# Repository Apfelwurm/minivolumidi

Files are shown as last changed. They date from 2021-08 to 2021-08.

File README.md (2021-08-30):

# minivolumidi Project

minivolumidi is a simple midi controller via wifi and [rtpMIDI](https://www.tobias-erichsen.de/software/rtpmidi.html) / apple network MIDI, based on a [Wemos D1 mini (ESP8266)](https://www.wemos.cc/en/latest/d1/d1_mini.html) and a KY-40 rotary encoder that is intended to act as a volume controller. By default a short button press sets the CC value to the configured ``MIN_POS`` and a long button press sets it back to the value before the short button press.

This project is based on the following sources:
* https://github.com/lathoub/Arduino-AppleMIDI-Library/tree/master/examples
* https://github.com/LennartHennigs/ESPRotary/tree/master/examples
* https://github.com/FortySevenEffects/arduino_midi_library/tree/master/examples
* https://www.thingiverse.com/thing:2814909
* https://www.thingiverse.com/thing:3646462

Thanks to all the nice people making qick projects like this possible by their contributions to the open source world! 

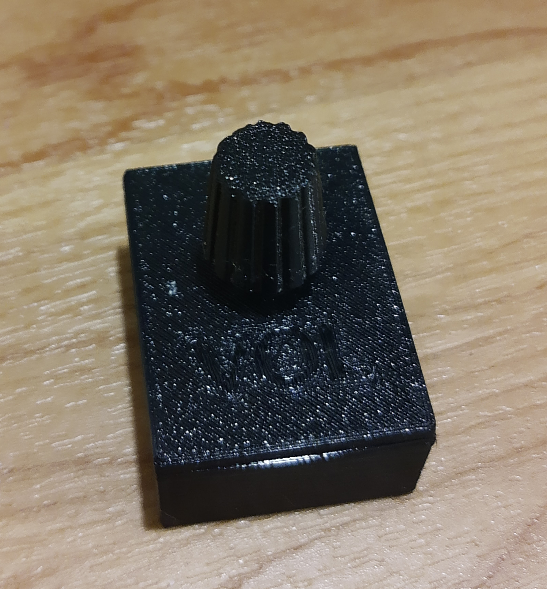
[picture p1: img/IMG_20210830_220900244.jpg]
minivolumidi

(more pictures in the ``img`` folder)

## prerequirements for building the hardware

* [Wemos D1 mini (ESP8266)](https://www.wemos.cc/en/latest/d1/d1_mini.html)
* a micro usb cable
* a KY-40 rotary encoder
* some wires
* soldering iron
* a 3d printer (if you want to print the case for it)
* hot glue gun
## prerequirements for building the software

* install [Platformio Core](https://docs.platformio.org/en/latest/core/installation.html) or [Platformio IDE](https://docs.platformio.org/en/latest/integration/ide/vscode.html#ide-vscode) (which installes Pio core automatically)
* clone this repository
```
git clone https://github.com/Apfelwurm/minivolumidi.git
```
## build (Visual Studio Code)

* open the cloned repo in VSCode

```
code minivolumidi
```

* open the ``src/main.cpp`` file and adapt the values in the configure section according to your requirements. 
* open the ``platformio.ini`` file and change the ``upload_port`` to your needs (most likely ``/dev/ttyUSB0`` on linux and ``COM3`` on windows)
* Press f5 to build it.
* Press the ``PlatformIO:Upload`` button at the bottom navigation of vscode to flash your wemos d1.

## build (CLI)

You can instead go to the repo folder with your terminal and run

```
pio run
```

respectively

```
pio run -t upload
```

depending if you want to just build or directly upload it to your wemos d1.

## enclosure

You can find a 3d printable enclosure and the rotary encoder knob files in the ``case`` subdirectory.
To print everything you can just use the ``case/wemos_stack_with_rotary_knob.stl`` in your favorite slicer.
For customizing of the case or if you dont want to print the knob, look into the ``case/wemos_stack.scad`` and adjust it to your needs.

## building the hardware

* print your case
* flash your Wemos d1
* bend the pins on your KY-40 rotary encoder so they face in the opposite direction as the rotary encoder or desolder them
* solder the KY-40s + pin to 3.3v of the Wemos
* solder the KY-40s GND pin to GND of the Wemos
* solder the KY-40s SW pin to configured ``BUTTON_PIN`` of the Wemos (dont use D8!) (default D5)
* solder the KY-40s CLK pin to configured ``ROTARY_PIN2`` of the Wemos (default D7)
* solder the KY-40s DT pin to configured ``ROTARY_PIN1`` of the Wemos (default D6)
* insert the KY-40 into the lid of the case (maybe you have to widen the hole a little bit for that)
* try to shorten the outstanding KY-40s pins on the bottom (be careful that you dont break something)
* fill the gapps between the KY40 and the lid with hotglue as good as possible and cover the whole back of the KY-40 with a 3-4mm thick layer of it. Be careful to clean all hot glue that will block the lids closing mechanism
* put the wemos in the case and close the lid with the KY-40 by pressing it together with the case
* put some hotglue into the rotary knob and press it on the rotary encoder
## using the hardware on windows

* install [rtpMIDI](https://www.tobias-erichsen.de/software/rtpmidi.html) on your target machine
* initially connect your minivolumidi via usb to your pc, open a serial terminal and press the small reset button on the left side with a needle. You should now get a serial print out of the IP address, the name and the port of your minivolumidi. 
* open rtpMIDI, add a session on the left side and enable it on the right side.
* add the minivolumidi in the ``Directory`` section with the data you gathered from the serial terminal
* press connect and test if it shows the connected client with a latency on the right side
* if everything works, you can now power the wemos everywhere in the wifi range of the configured network, without the usb connection and connect it via rtpMIDI
* open your DAW of choise and enable the rtpMIDI input and output channels
* map the midi parameter to whatever you want to control with it. Because of the wifi latency its not really useful for instant controls, but its perfect as a simple volume controller.

## contributions

if you want to contribute to the project or if you have problems, dont hesitate to open issues or submit pull requests.

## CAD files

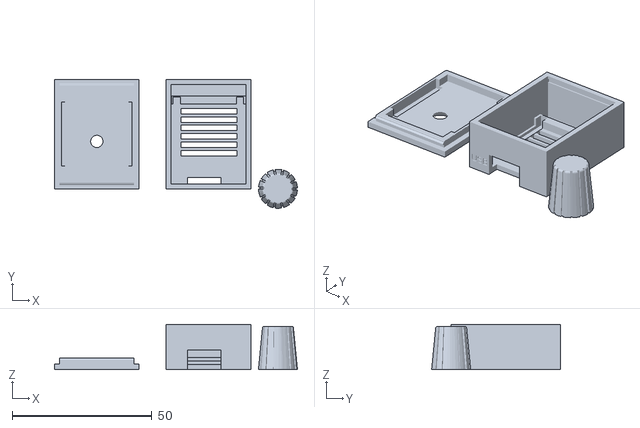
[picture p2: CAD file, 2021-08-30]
case/wemos_stack_with_rotary_knob.stl
87.0 x 46.1 x 16.2

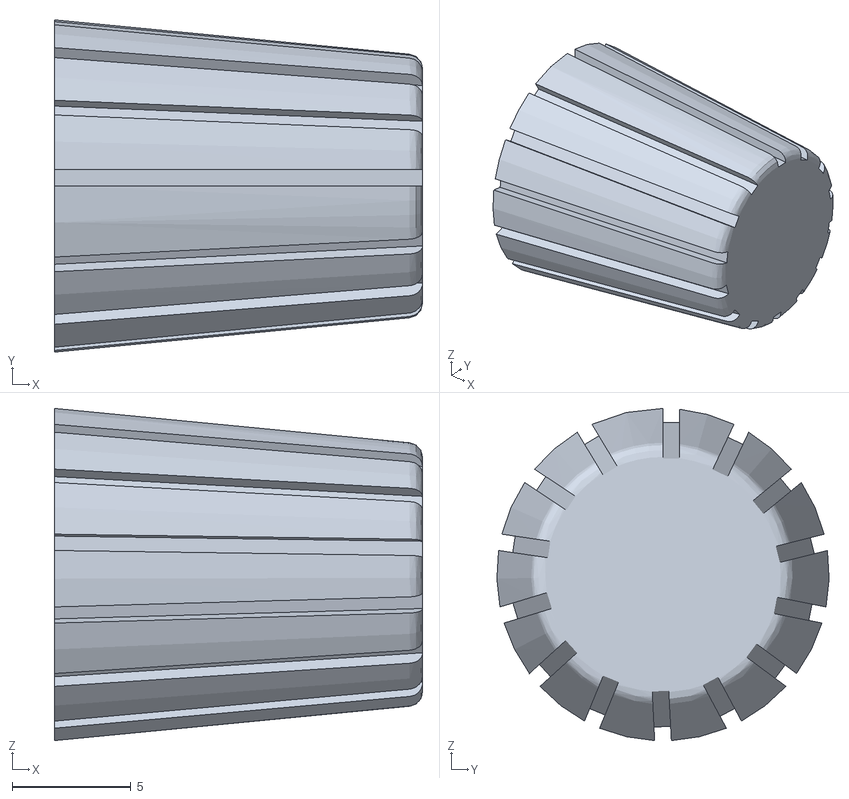
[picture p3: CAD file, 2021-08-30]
case/Drehregler7.stl
15.5 x 14.0 x 14.0

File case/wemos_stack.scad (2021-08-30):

// This Version is based on https://www.thingiverse.com/thing:2814909 and the Rotary Encoder Cap is used from https://www.thingiverse.com/thing:3646462
//
// WeMOS D1 Mini Stack Enclosure Script
// This Version is inspired from https://www.thingiverse.com/thing:1776349/#files
//
// This script was written to generate a suitable 3D printed enclosure for a WeMOS "stack" of shields.
// Since there are a variety of connectors, sizes and arrangements, the decission was to let the customizer
// allow for various positionings of each shields port.
//
// To use, you will need to assemble your device put it on a flat surface (e.g. table) and measureeach layer. 
// For measuring you need the distance from your flat surface to the lower end of the opening in the case.
//  - the total innerSizeZ (height) of the stack
//  - the inner offsets for any shields that require an opening in the case.
//
// For instance, We have the following Stack:
//
// +----------------+
// | SD Card Shield |
// +----------------+
// | Battery Shield |
// +----------------+
// | WeMOS D1 Mini  |
// +----------------+ 2 mm
//
// All have stackable headers, that have had their pins trimmed to make the stack as short
// as possible.  The resulting measurements of the stack yield the default values of this script.
//

/* [inner Height Z] */
// Final height of the stack measured when placing the sole stack on a flat surface.
//innerHeightZ = 58.7;
innerHeightZ = 14.4;


/* [Shield Ports] */

// Distance from the bottom of PCB Board to the bottom of the usb connector opening (-99 to omit)
usbHeight = -1.0;

// Distance from the bottom of PCB Board to the bottom of the microsd shield opening (-99 to omit)
//microsdHeight = 30;
// microsdHeight = 8;
 microsdHeight = -99;

// Distance from the bottom of PCB Board to the bottom of the battery shield connector opening (-99 to omit)
//batteryHeight = 18.0;
//batteryHeight = 15;
batteryHeight = -99;

// Distance from the bottom of PCB Board to the bottom of the DC Power shield connector terminal opening (-99 to omit)
//dcPowerHeight=25;
dcPowerHeight=-99;

// Distance from the bottom of PCB Board to the bottom of the relay shield connector terminal opening (-99 to omit)
relayHeight = 38.0;

// Show Base housing
showBase=true;

/* [LID] */

// There are visible cutouts in the lid for 
lidHasVisiblePinoutSlits=false;

// The lid should contain a cutout connecting the PINs
lidCutOutType="LED"; // [ LCD:LCD Shield , DHT:Dht Shield,DHThorizontal:Dht Shield, BUTTON:Button Shield , NONE:No cutout]

// Do you want the Lid to show up
showLid=true;

//Side and Front slits for letting warm air out
airSlits=false;

/* [Others] */
wallThickness = 1.8;

// cut through at Bottom for Pins
bottomHasPinoutSlits=true;

// Add mounting clips with screw holes a bottom
numberOfBaseMountingClips=0;

// show some Examples
showExamples=false;

// show each Tape once
showAllOnce=false;

// ---------------------------------------------------------------------------------------------------------
// do not need to modify anything below here
// ---------------------------------------------------------------------------------------------------------
/* [Hidden] */

extraGap=0.2;
printerWobble=0.01;
printerWobbleXYZ=printerWobble*[1,1,1];
printerWobbleXYZ2=printerWobbleXYZ*2;

$fn=20;

// Final outerSizeZ of the stack walls.
// outerSizeZ = 36.0;

innerSizeX = 26.70;
innerSizeY = 35.5;
//innerSizeZ = innerHeightZ;


holeDiameter = 20.0;

// Offset of all stacked Boards because of the WIFI Antenna
antennaOffsetY=6.2;
lcdDimensions=[18.5,18.1,4.5]
              +2*printerWobble*[1,1,0];

// Size of the slits for pins of PCB board
slitDimension=[2.6,23.0,10.0];


/* calculated */
extraGap2=2*extraGap;


// ===================================================
// Rotary knob - https://www.thingiverse.com/thing:3646462
// ===================================================

translate([40,0,0])rotate([0,270,0])
import("Drehregler7.stl");

// ===================================================
// Main
// ===================================================

if (showAllOnce){
    translate([0,-50,0])  
        LidExamples();
    
    BaseExamples();

} else {

    // base
    if (showBase)
        base(innerSizeZ=innerHeightZ-wallThickness,numberOfBaseMountingClips=numberOfBaseMountingClips);

    // lid
    if (showLid)
        translate([-40,0,0])   
            lid(lidCutOutType=lidCutOutType);


    // All kind of examples
    if ( showExamples)
        translate([0,200,0])  
            examples();

}

// ===================================================
// Modules
// ===================================================

module examples(){
    translate([0,-50,0])  {
        LidExamples();
    translate([0,-45,40])  
        rotate([270,0,0]) 
            LidExamples();
    }
    
    BaseExamples();

}


module BaseExamples(){
        translate([0,0,0])   {
            translate([000,0,0])     base(innerSizeZ=17,        numberOfBaseMountingClips=0);
            translate([050,0,0])     base(innerSizeZ=17,        numberOfBaseMountingClips=2);
            translate([100,0,0])     base(innerSizeZ=17,        numberOfBaseMountingClips=4);
        }
        
        translate([0,60,0])  {
            translate([000,0,0])     base(innerSizeZ=12.5, numberOfBaseMountingClips=0);
            translate([040,0,0])     base(innerSizeZ=22.5, numberOfBaseMountingClips=0);
            translate([080,0,0])     base(innerSizeZ=36,   numberOfBaseMountingClips=0);
            translate([120,0,0])     base(innerSizeZ=47,   numberOfBaseMountingClips=0);
        }
        
        translate([0,120,0])   {
            translate([000,0,0])     base(innerSizeZ=27);
            translate([040,0,0])     base(innerSizeZ=27, dcPowerHeight=12,  microsdHeight=0, batteryHeight=0, relayHeight=0 , numberOfBaseMountingClips=0);
            translate([080,0,0])     base(innerSizeZ=27, dcPowerHeight=0,  microsdHeight=12, batteryHeight=0, relayHeight=0 , numberOfBaseMountingClips=0);
            translate([120,0,0])     base(innerSizeZ=27, dcPowerHeight=0,  microsdHeight=0, batteryHeight=12, relayHeight=0 , numberOfBaseMountingClips=0);
            translate([160,0,0])     base(innerSizeZ=27, dcPowerHeight=0,  microsdHeight=0, batteryHeight=0, relayHeight=12 , numberOfBaseMountingClips=0);
        }

}

module LidExamples(){
        translate([000,0,0])   lid(lidCutOutType="BUTTON");
        translate([040,0,0])   lid(lidCutOutType="LCD");
        translate([080,0,0])   lid(lidCutOutType="DHT");
        translate([120,0,0])   lid(lidCutOutType="HOLE");
        translate([160,0,0])   lid(lidCutOutType="NONE");

}


module lcdCutOut(){
   cube(lcdDimensions+extraGap*[1,1,0]);

    // Flat cable for connection
    cableX=14;
    cableY=6;
    cableZ=4;
    translate([lcdDimensions[0]/2-cableX/2,-cableY+.001,.5])
        cube([cableX,cableY,cableZ]);
}


module pinHoleSlits(visibleFromOutside=1){
    
    slitOffsetY=wallThickness
                +innerSizeY
                -slitDimension[1]
                -antennaOffsetY;
    
    translate([0,0,visibleFromOutside==1?-.01:+.8])
        translate([.7,slitOffsetY,0])
            for ( x=[0,22.6]){
                translate([x,0,0])
                    cube(slitDimension);
            }
}


// ========================================
// Lid
// ========================================

module lid(lidCutOutType="BUTTON"){
    outerSizeX = innerSizeX + (2 * wallThickness);
    outerSizeY = innerSizeY + (2 * wallThickness);
//    outerSizeZ = innerSizeZ + (2 * wallThickness);
    diameterButton=8;
    
    difference() {
        union () {
            // Lid Base Plate
            translate([0, 0, 0.0]) cube([outerSizeX, outerSizeY, 2.0]);

            // Lid inner part
            translate([ wallThickness+printerWobble, wallThickness+printerWobble,wallThickness]) {
                color("green")
                    cube([innerSizeX-2*printerWobble, innerSizeY-2*printerWobble, 2.3]);
                LidNotch(wobble=-1);
             }
        }
        
        // Space for PCB Board
        innerFrameOffset=2;
        translate([ wallThickness+innerFrameOffset, wallThickness+innerFrameOffset,wallThickness]) 
                cube([innerSizeX-innerFrameOffset*2, innerSizeY-innerFrameOffset*2, 4]);
        
        translate([wallThickness,0,0])
            pinHoleSlits(visibleFromOutside=lidHasVisiblePinoutSlits);
        
        // Lid Cutout
        if(lidCutOutType=="LCD"){
                translate(wallThickness*[1,1,-0.001]
                        +[innerSizeX/2,innerSizeY,0])
                        translate([-lcdDimensions[0]/2,-lcdDimensions[1],0]
                                  +[0,-antennaOffsetY,0]
                                ) 
                            lcdCutOut();
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

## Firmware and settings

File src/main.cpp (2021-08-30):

// minivolumidi main script
// packed together by Apfelwurm <Alexander@volzit.de>
// based on the following sources:
// https://github.com/lathoub/Arduino-AppleMIDI-Library/tree/master/examples
// https://github.com/LennartHennigs/ESPRotary/tree/master/examples
// https://github.com/FortySevenEffects/arduino_midi_library/tree/master/examples

#include <ESP8266WiFi.h>
#include <WiFiClient.h>
#include <WiFiUdp.h>
#include <AppleMIDI.h>
#include <Arduino.h>
#include "Button2.h" 
#include "ESPRotary.h"

/////////////////////////////////////////////////////////////////
// Configure your needs here
/////////////////////////////////////////////////////////////////
char ssid[] = "SSID"; //  your network SSID (name)
char pass[] = "PASSWORD";    // your network password (use for WPA, or use as key for WEP)


#define ROTARY_PIN1 D6 // DT pin of ky-040
#define ROTARY_PIN2 D7 // CLK pin of ky-040
#define BUTTON_PIN  D5 // SW pin of ky-040

#define CLICKS_PER_STEP 2   // this number depends on your rotary encoder
#define MIN_POS         0   // minimum value for the knob
#define MAX_POS         127 // maximum value for the knob
#define START_POS       20  // starting position for the knob
#define INCREMENT       1   // this number is the counter increment on each step

#define MIDI_CC         91  //CC Number that should be used
#define MIDI_CHANNEL    1   // Midi Channel that should be used
/////////////////////////////////////////////////////////////////

/////////////////////////////////////////////////////////////////
// varible initialisation
/////////////////////////////////////////////////////////////////
bool newpos = false;
bool mute = false;
bool unmute = true;
unsigned long t0 = millis();
int8_t isConnected = 0;
/////////////////////////////////////////////////////////////////

/////////////////////////////////////////////////////////////////
// object initialisation
/////////////////////////////////////////////////////////////////
APPLEMIDI_CREATE_DEFAULTSESSION_INSTANCE();
ESPRotary r;
Button2 b;    // https://github.com/LennartHennigs/Button2
/////////////////////////////////////////////////////////////////



/////////////////////////////////////////////////////////////////
// Rotary encoder functions
/////////////////////////////////////////////////////////////////

// on change
void rotate(ESPRotary& r) {
   Serial.println(r.getPosition());
   newpos = true;
}

// on left or right rotation
void showDirection(ESPRotary& r) {
  Serial.println(r.directionToString(r.getDirection()));
}

// single click
void click(Button2& btn) {
  mute=true;
  Serial.println("Click!");
}

// long click
void resetPosition(Button2& btn) {
  unmute = true;
  Serial.println("Reset!");
}

/////////////////////////////////////////////////////////////////


/////////////////////////////////////////////////////////////////
// setup
/////////////////////////////////////////////////////////////////
void setup() {

  //serial setup
  Serial.begin(115200);

  delay(50);

  //wifi setup
  WiFi.begin(ssid, pass);

  while (WiFi.status() != WL_CONNECTED) {
    delay(500);
    Serial.println("Establishing connection to WiFi..");
  }
  Serial.println("Connected to network");

  //RTP Midi setup
  Serial.println(F("OK, now make sure you an rtpMIDI session that is Enabled"));
  Serial.println(WiFi.localIP().toString()); 
  Serial.println(AppleMIDI.getPort()); 
  Serial.println(AppleMIDI.getName()); 
  Serial.println(F("Select and then press the Connect button"));
  Serial.println(F("Then open a MIDI listener and monitor incoming notes"));
  Serial.println(F("Listen to incoming MIDI commands"));
 
  MIDI.begin();
  
 AppleMIDI.setHandleConnected([](const APPLEMIDI_NAMESPACE::ssrc_t & ssrc, const char* name) {
    isConnected++;
    Serial.println(F("Connected to session"));
    Serial.println(ssrc); 
    Serial.println(name); 

  });
  AppleMIDI.setHandleDisconnected([](const APPLEMIDI_NAMESPACE::ssrc_t & ssrc) {
    isConnected--;
    Serial.println(F("Disconnected"));
    Serial.println(ssrc); 
  });
  
 
  //button setup
  b.begin(BUTTON_PIN);
  b.setTapHandler(click);
  b.setLongClickHandler(resetPosition);

  //rotary setup
  r.begin(ROTARY_PIN1, ROTARY_PIN2, CLICKS_PER_STEP, MIN_POS, MAX_POS, START_POS, INCREMENT);
  r.setChangedHandler(rotate);
  r.setLeftRotationHandler(showDirection);
  r.setRightRotationHandler(showDirection);

  //init output
  Serial.println("\n\nminivolumidi");
  Serial.println("Is configured for values between " + String(MIN_POS) + " and " + String(MAX_POS) +".");
  Serial.print("Increment: ");
  Serial.println(r.getIncrement());
  Serial.print("Current position: ");
  Serial.println(r.getPosition());
  Serial.println();
}
/////////////////////////////////////////////////////////////////


/////////////////////////////////////////////////////////////////
// loop
/////////////////////////////////////////////////////////////////
void loop() {
  
  //RTPMIDI processing
  MIDI.read();

  //rotary processing
  r.loop();

  //button processing
  b.loop();

  if ((isConnected > 0) && (millis() - t0) > 1000)
  {
    t0 = millis();

    // mute and unmute
    if (mute){
      MIDI.sendControlChange((byte)MIDI_CC,(byte)MIN_POS,MIDI_CHANNEL);
      mute=false;
    }
    if (unmute)
    {     
      MIDI.sendControlChange((byte)MIDI_CC,(byte)r.getPosition(),MIDI_CHANNEL);
      unmute=false;
    }

    // value update
    if (newpos)
    {
      MIDI.sendControlChange((byte)MIDI_CC,(byte)r.getPosition(),MIDI_CHANNEL);
      newpos = false;
    }



  }

}
/////////////////////////////////////////////////////////////////

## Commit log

2021-08-27 fixed button and added mute
    [main.cpp]
2021-08-30 added initial case from https://www.thingiverse.com/thing:2814909
    [wemos_stack.scad]
2021-08-30 updated wemos case and added rotary cap from https://www.thingiverse.com/thing:3646462
    [Drehregler7.stl, wemos_stack.scad]
2021-08-30 removed wrong build script, updated documentation, fixed hole size, added full stl
    [wemos_stack.scad, wemos_stack_with_rotary_knob.stl]
